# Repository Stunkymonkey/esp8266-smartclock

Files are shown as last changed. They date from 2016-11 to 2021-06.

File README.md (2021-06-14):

# esp8266-smartclock

We started designing and building a small clock that is connected to your local Wifi and controls your home using cheap 433Mhz power outlets. The ESP8266 operates as a relay to communicate with your power outlets.

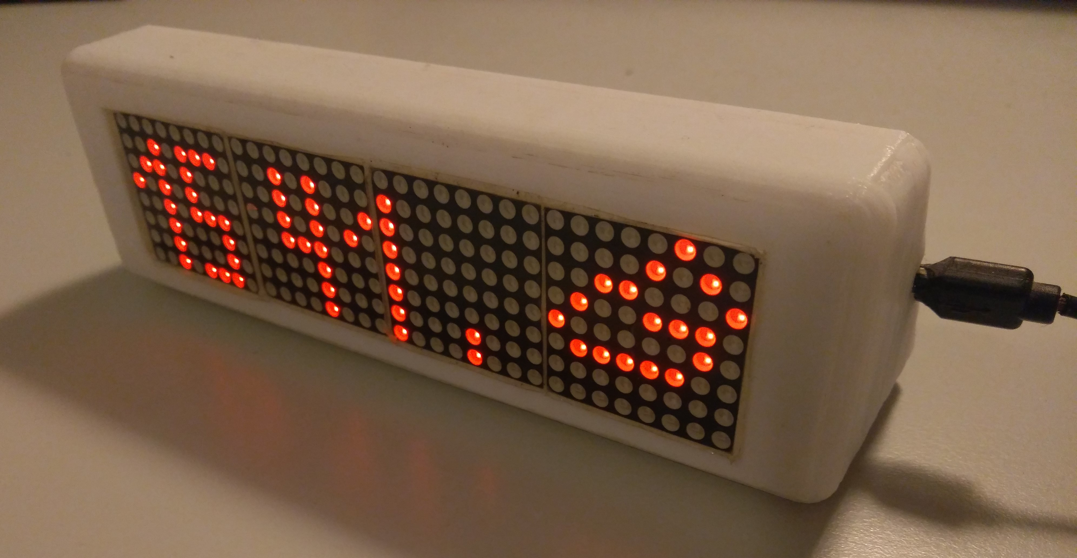
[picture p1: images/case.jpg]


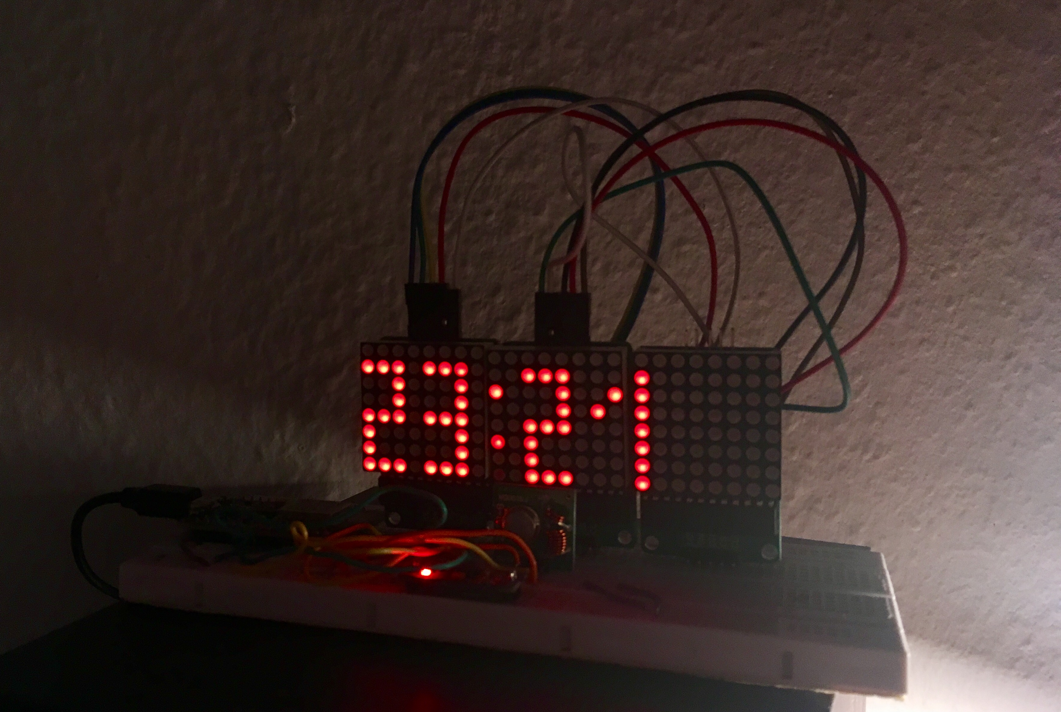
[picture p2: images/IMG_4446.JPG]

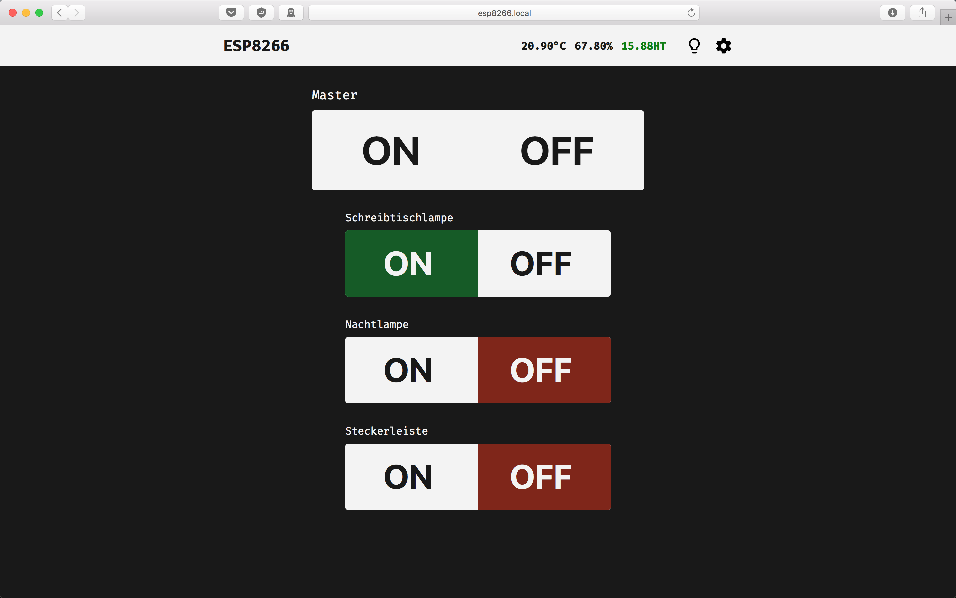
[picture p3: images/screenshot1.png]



## Hardware
The total costs are around 25€:

* NodeMCU board with the ESP8266 and an USB programmer
* DHT11 or DHT22 (optional)
* 433Mhz transmitter (XD-RF-5V)
* 4x MAX7219 based 8x8 led matrix
* 433mhz Wireless Remote Control Electrical Outlet Switch (<a href="https://www.amazon.de/dp/B001AX8QUM/ref=cm_sw_em_r_mt_dp_Abo7zbDRGS07B">example</a>) 
* some wires

### Schematic
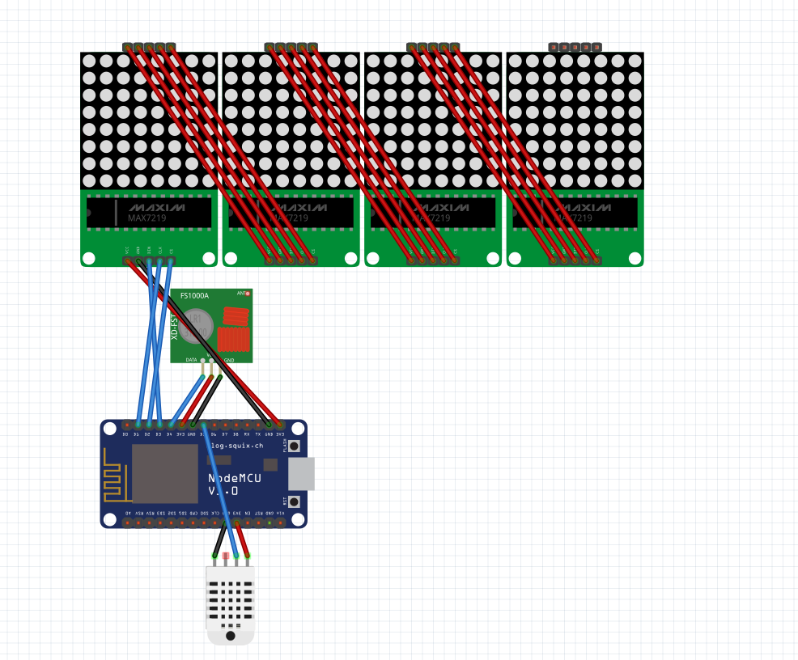
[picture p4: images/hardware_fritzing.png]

<a href="esp8266_smartclock.fzz">Fritzing File</a>

## Features
* opens an access point to enter your local Wifi SSID and password
* customisable slots for your power outlets
* custom brightness settings for the LED matrix
* Read Data from a DHT11 temperature and humidity sensor and send it to a remote Host (for saving the data see: sensor.php)
* NTP Time support
* supports multiple Wireless Remote Control protocols (we are using the <a href="https://github.com/sui77/rc-switch">rc-switch</a> library)
* dyndns (using a get request on a given url every 10 minutes)
* password-authentication for user from the internet (no https 😞)
* OverTheAir Update

## Development

### Dependencies

| Module | last tested version |
| --- | --- |
| [ESP8266](https://github.com/esp8266/Arduino) | 2.7.1 |
| [NTPClient](https://github.com/arduino-libraries/NTPClient)  | 3.2.0 |
| [Adafruit_Sensor](https://github.com/adafruit/Adafruit_Sensor) | 1.1.3 |
| [DHT-sensor-library](https://github.com/adafruit/DHT-sensor-library) | 1.3.10 |
| [LedControl](http://wayoda.github.io/LedControl/) | 1.0.6 |
| [rc-switch](https://github.com/sui77/rc-switch) | 2.6.3 |
| [Time](http://playground.arduino.cc/code/time) | 1.6.0 |

### Board-Settings (used)

- Board: NodeMCU 1.0 (ESP-12E Module)
- Builtin Led: 2
- Upload Speed: 115200
- CPU Frequency: 80Mhz
- Flash Size: 4MB (FS:1MB OTA:~1019KB)
- Debug Port: Disabled
- Debug Level: None
- lwIP Variant: v2 Lower Memory
- VTables: Flash
- Exceptions: Enabled
- Erase Flash: Only Sketch
- SSL Support: All SSL ciphers (most compatible)

### Compile
```
arduino ./ESP_clock/ESP_clock.ino --verify --preserve-temp-files
```

### Update via OTA
```
curl -u admin:admin -F "image=@$(find /tmp/arduino* -name 'ESP_clock.ino.bin')" esp8266/update
```
or via webinterface at `http://esp8266/update`

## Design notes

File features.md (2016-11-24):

+ Steckdosen an/auschalten [HTTP, Webseite]
+ Pixel an/auschalten [HTTP, Webseite]
+ Konfiguration im EEPROM:
	+ Steckdosen bennenen
	+ initalier AP zur Eingabe von SSID und Pwd

+ Uhrzeit via NTP abfragen
	+ Uhrzeit auf Display anzeigen
	+ Konfiguration
+ Temperatur und Feuchtigkeit auslesen und per API zur Verfügung stellen
+ startup animation
+ Hardware Switch mit (programmierbarer Aktion)

## Optional:

+ Helligkeit messen
+ sockets delayed auschalten

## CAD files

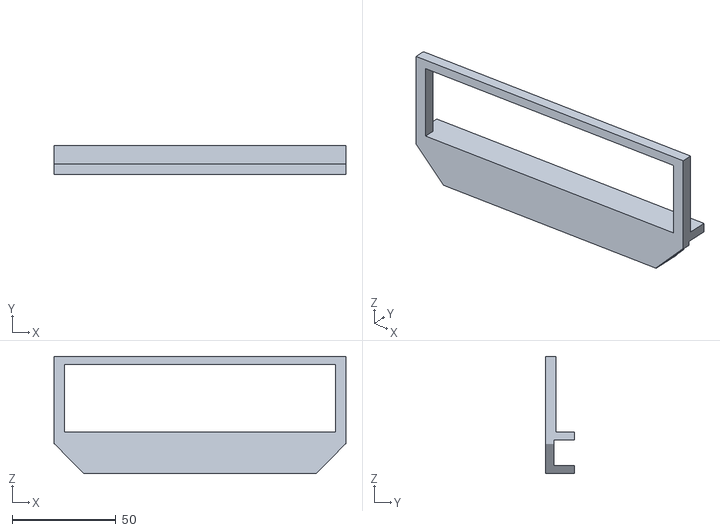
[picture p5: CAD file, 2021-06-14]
3d-printing/smartclock_case_to_mount_on_plank.stl
140.5 x 14.0 x 56.5

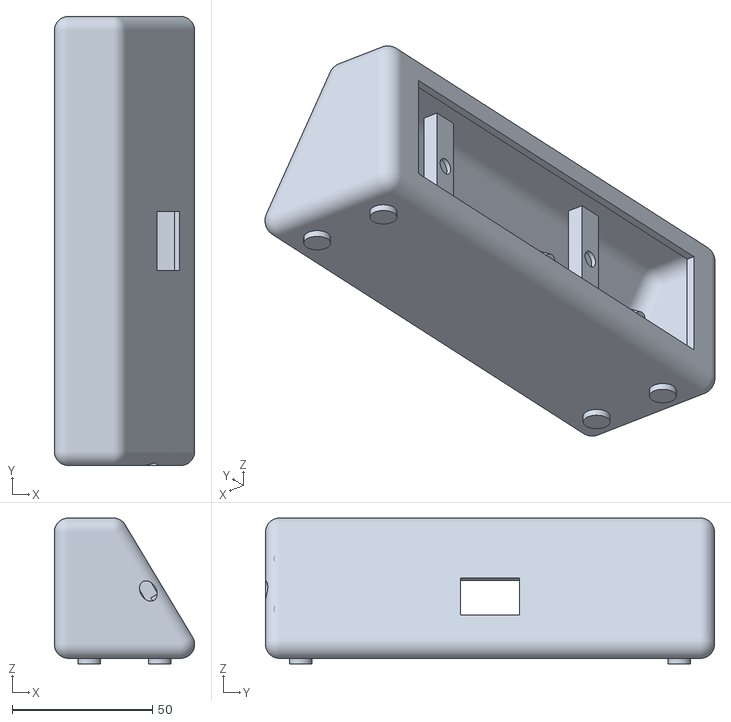
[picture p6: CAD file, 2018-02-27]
3d-printing/smartclock.stl
50.0 x 160.0 x 52.0

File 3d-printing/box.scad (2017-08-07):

$fn=30;

// x = height
// y = widht
// zb = depth bottom
// zt = depth top
// t = thikness
// r = radius of round corner
// dispx = display height
// dispy = display width
// side = {true == left / false == right}
module box(x, y, zb, zt, t, r, dispx, dispy, side) {
    angle = atan(x/(zb-zt));
    new_x = x-2*r;
    new_y = y-2*r;
    new_zb = zb-2*r;
    move_of_hollow = (zb/2)/cos(90-angle);
    difference(){
        minkowski(){
            difference(){
                cube([new_x,new_y,new_zb], center = true);
                translate([move_of_hollow+(new_zb/2),0,-(new_x/2)])
                    rotate(angle, [0, 1, 0])
                        cube([10*x,y+1,zb], center = true);
            }
            sphere(r);
        }
        
        //Cut out ledge
        translate ([(-zb/2)+1,0,0]) cube([10, dispy, dispx], center = true);
        
        //Hollow inside
        minkowski(){
            difference(){
                cube([new_x-2*t,new_y-2*t,new_zb-2*t], center = true);
                translate([move_of_hollow+(new_zb/2-2*t),0,-(new_x/2)])
                    rotate(angle, [0, 1, 0])
                        cube([10*x-2*t,y+1-2*t,zb-2*t+0.5], center = true);
            }
            sphere(r);
        }
        
        side_position = side ? y/2 : -y/2 ;
        translate([0, side_position, -zb/10])
            rotate(angle, [0, 1, 0])
            rotate(90, [1, 0, 0])
                linear_extrude(height = r*2, center = true, convexity = 10, twist = 0)
                    scale([(sqrt(2)/2)*1.1,(sqrt(2)/2)*0.8,1])
                        circle(r = 5);
        
//        translate([x/2-1,0,-(new_x/2)])
//            rotate(angle, [0, 1, 0])
//                cube([90, new_y-2*r, 2], center = true);
//        translate([x/2,0,-(new_x/2)])
//            rotate(angle, [0, 1, 0])
//                cube([90, new_y-4*r, 2], center = true);
        
        //cube([new_x*2, new_y*0.2, new_zb*2], center = true);
    }
    translate([10, y/4, 0])
        rotate(180+angle, [0, 1, 0])
                esp_mount(3, 2);
    translate([0, 0, -zb/2])
        stands(4, 2, 10, x, y, zb, 10);
}

// height_front = front distance to floor
// height_back = back distance to floor
// diameter = radius of stands
// x = size of bottom in x
// y = size of bottom in y
// zb = size of bottom in z
// distance = position: distance from edges
module stands(height_front, height_back, diameter, x, y, zb, distance) {
    difference() {
        union(){
            translate([-x/2+distance, y/2-distance,-height_front/2])
                cylinder(d=diameter, h=height_front, center=true);
            translate([+x/2-distance, y/2-distance,-height_front/2])
                cylinder(d=diameter, h=height_front, center=true);
            translate([-x/2+distance, -y/2+distance,-height_front/2])
                cylinder(d=diameter, h=height_front, center=true);
            translate([+x/2-distance, -y/2+distance,-height_front/2])
                cylinder(d=diameter, h=height_front, center=true);
        }
        angle = atan((height_front-height_back)/zb);
        translate([-x/2, 0, -zb/2-(height_front)])
            rotate(angle, [0, -1, 0])
                cube([x*2, y, zb], center=true);
    }
}

module esp_mount(height, depth) {
    XDim = 25.0;
    YDim = 48.0;
    HD = 2.5; //are in reality 3.0
    hole_size = 1.5;
    HXO = 2.0;
    HYO = 2.2;
    difference() {
        translate([-XDim/2+HXO, YDim/2-HYO,0])
            cylinder(d=HD, h=height*2, center=true);
        translate([-XDim/2+HXO, YDim/2-HYO,2*height-depth])
            cylinder(d=hole_size, h=height*2, center=true);
    }
    difference() {
        translate([XDim/2-HXO, YDim/2-HYO,0])
            cylinder(d=HD, h=height*2, center=true);
        translate([XDim/2-HXO, YDim/2-HYO,2*height-depth])
            cylinder(d=hole_size, h=height*2, center=true);
    }
    difference() {
        translate([-XDim/2+HXO, -YDim/2+HYO,0])
            cylinder(d=HD, h=height*2, center=true);
        translate([-XDim/2+HXO, -YDim/2+HYO,2*height-depth])
            cylinder(d=hole_size, h=height*2, center=true);
    }
    difference() {
        translate([XDim/2-HXO, -YDim/2+HYO,0])
            cylinder(d=HD, h=height*2, center=true);
        translate([XDim/2-HXO, -YDim/2+HYO,2*height-depth])
            cylinder(d=hole_size, h=height*2, center=true);
    }
}

box(50, 160, 50, 20, 2, 5, 32, 133, true);

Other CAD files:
3d-printing/smartclock.scad

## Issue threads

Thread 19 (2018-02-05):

On/Off - Button have white corners

Stunkymonkey, 2018-02-05:
if they are red i noticed, that they have a white corner
maybe also if they are green

Stunkymonkey, 2018-02-05:
green is also affected

Stunkymonkey, 2019-07-13:
rendering issue

Closed 2019-07-13.

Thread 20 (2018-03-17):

Boot Loop Crash

friedrichweise, 2018-03-17:
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

Stunkymonkey, 2018-03-30:
still not working?

friedrichweise, 2018-04-14:
Fixed by formatting the file system.

friedrichweise, 2018-04-14:
linked to https://github.com/esp8266/Arduino/issues/4417

Closed 2018-12-28.

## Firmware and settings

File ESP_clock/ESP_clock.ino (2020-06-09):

// IMPORTS
extern "C" {
#include "user_interface.h"
}
#include <ArduinoOTA.h>
#include <DHT.h>
#include <DNSServer.h>
#include <ESP8266HTTPClient.h>
#include <ESP8266HTTPUpdateServer.h>
#include <ESP8266mDNS.h>
#include <ESP8266WebServer.h>
#include <ESP8266WiFi.h>
#include <FS.h>
#include <LedControl.h>
#include <LittleFS.h>
#include <NTPClient.h>
#include <RCSwitch.h>
#include <SoftwareSerial.h>
#include <TimeLib.h>
#include <WiFiClient.h>
#include <WiFiClientSecure.h>
#include <WiFiUdp.h>

//include personal config
#include "config.h"
#include "victron.h"

// GLOBAL VARIABLES
String deviceName = "";

String WifiSsid = "";
String WifiPw = "";

String configSocketSets[SOCKET_AMOUNT][5];
boolean statusSocketSets[SOCKET_AMOUNT];

LedControl lc = LedControl(LED_MATRIX_PORT_DATA,        LED_MATRIX_PORT_CLK, \
                           LED_MATRIX_PORT_CHIP_SELECT, LED_MATRIX_PORT_AMOUNT);
int led_matrix_intensity;
boolean MatrixStatus = true;

int prevMin1 = -1;
int prevMin2 = -1;
int prevHour1 = -1;
int prevHour2 = -1;
int prevWeather = 12;
int prevSecond = -1;
boolean prevBlink = false;

boolean isAPMode = false;

ESP8266WebServer server(80);
//used to combine webpages in createServer();
String content;
String DEBUG_STRING = "";

//OTA-Server
ESP8266HTTPUpdateServer httpUpdater;

//AP-Settings
DNSServer dnsServer;

//Socket-remote
RCSwitch mySwitch = RCSwitch();

//Temperature and Humidity
DHT dht(SENSOR_PORT, SENSOR_TYPE);
float humidity, temperature, heatindex;

//NTP
WiFiUDP ntpUDP;
NTPClient timeClient(ntpUDP, NTP_SERVER, 0, NTP_INTERVAL);

//HTTP
std::unique_ptr<BearSSL::WiFiClientSecure> client_secure(new BearSSL::WiFiClientSecure);
WiFiClient client;
HTTPClient http;

//WEATHER
int weatherStatus = -1;

void (* Disco_Functions[3])(void);
bool DiscoStatus = false;
int DiscoState = 0;
int DiscoTmp = 0; //shared storage for all disco-functions

// Victron
SoftwareSerial victronSerial(VICTRON_RX, VICTRON_TX);
char receivedChars[buffsize];
char tempChars[buffsize];
char recv_label[num_keywords][label_bytes]  = {0};
char recv_value[num_keywords][value_bytes]  = {0};
char value[num_keywords][value_bytes]       = {0};
static byte blockindex = 0;
bool new_data = false;
bool blockend = false;

void setup()
{
  //Serial-Output
  if (DEBUG) {
    Serial.begin(115200);
  }
  print("Starting setup");
  // start vicront serial
  if (ENABLE_VICTRON) {
    victronSerial.begin(19200);
  }
  //enable LEDs
  pinMode(LED_BUILTIN, OUTPUT);
  pinMode(2, OUTPUT);
  LEDOn();
  WifiLEDOff();
  setProgress(266 / 8593.0);

  //mount File-System
  bool mountFs = LittleFS.begin();
  if (!mountFs) {
    print("Failed to mount File-System!");
  }
  setProgress(341 / 8593.0);

  //init Led-Matrixes:
  if (ENABLE_MATRIX) {
    led_matrix_intensity = loadIntensity();
    initMatrix(led_matrix_intensity);
  }
  setProgress(348 / 8593.0);

  //load device Name
  deviceName = loadDeviceName();
  setProgress(434 / 8593.0);
  //load sockets
  if (ENABLE_SOCKETS) {
    loadSocketSets();
  }
  setProgress(510 / 8593.0);

  //init wifi access point
  initWifi();
  setProgress(7213 / 8593.0);

  //network stuff
  createServer();
  setProgress(7229 / 8593.0);

  // OTA enable
  if (ENABLE_OTA) {
    httpUpdater.setup(&server, "/update", OTA_USERNAME, OTA_PASSWORD);
  }
  setProgress(7230 / 8593.0);

  // Http-Server start
  server.begin();
  setProgress(7247 / 8593.0);

  //service announcement
  if (ENABLE_MDNS) {
    // currently there is a bug, so this should be change back in the future to:
    // MDNS.begin(deviceName)
    if (!MDNS.begin(deviceName, WiFi.localIP(), 120)) {
      print("Error setting up MDNS responder!");
    }
    //WiFi.localIP().toString()
    MDNS.addService("http", "tcp", 80);
    MDNS.notifyAPChange();
  }

  //NTP-init
  timeClient.begin();
  timeClient.forceUpdate();
  timeClient.setTimeOffset(calculate_offset());
  setProgress(7319 / 8593.0);

  //RC-Switch
  if (ENABLE_SOCKETS) {
    mySwitch.enableTransmit(SOCKET_PORT);
  }

  if (ENABLE_SENSOR) {
    dht.begin();
    getTemperature();
  }
  setProgress(7593 / 8593.0);

  sendSensorData();
  setProgress(7702 / 8593.0);

  getWeatherInfo();
  setProgress(7814 / 8593.0);

  updateDYNDNS();
  setProgress(8265 / 8593.0);

  // fingerprint verification is skipped
  client_secure->setInsecure();

  Disco_Functions[0] = { random_pixel };
  Disco_Functions[1] = { cosine_wave };
  Disco_Functions[2] = { waterworld };
  LEDOff();
  WifiLEDOff();
  setProgress(1.0);
  //yolo();
}


void loop()
{
  server.handleClient();
  if (ENABLE_MDNS) {
    MDNS.update();
  }
  getTemperature();
  if (!isAPMode) {
    timeClient.update();
    timeClient.setTimeOffset(calculate_offset());
    sendSensorData();
    getWeatherInfo();
    updateDYNDNS();
  }
  victron();
  if (ENABLE_MATRIX && MatrixStatus) {
    if (!DiscoStatus) {
      drawTime();
      drawSecondsGraph();
      drawWeather(weatherStatus, 3);
    } else {
      draw_disco();
    }
  }
}

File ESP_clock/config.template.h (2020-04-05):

//PERSONAL-CONFIG-FILE

//DEBUG
const bool    DEBUG = false;
const unsigned int     REACTION_TIME = 500;

//SERVICES
const bool    ENABLE_SOCKETS = true;
const bool    ENABLE_SENSOR = true;
const bool    ENABLE_POST_SENSOR_DATA = false;
const bool    ENABLE_MATRIX = true;
const bool    ENABLE_DYNDNS = false;
const bool    ENABLE_MDNS = false;
const bool    ENABLE_LOGIN = true;
const bool    ENABLE_LOCAL_NO_LOGIN = true;
const bool    ENABLE_OTA = true;
const bool    ENABLE_WEATHER = true;
const bool    ENABLE_VICTRON = false;

//DEVICE-NAME
const String  DEFAULT_DEVICE_NAME = "ESP8266";

//LOGIN
const char    WWW_USERNAME[] = "admin";
const char    WWW_PASSWORD[] = "password";

//FIRMWARE
const char    OTA_USERNAME[] = "admin";
const char    OTA_PASSWORD[] = "admin";

//NTP
const char    NTP_SERVER[] = "pool.ntp.org";
const int     NTP_TIMEZONE = 1;     // Central European Time
//const int     NTP_TIMEZONE = -5;  // Eastern Standard Time (USA)
//const int     NTP_TIMEZONE = -4;  // Eastern Daylight Time (USA)
//const int     NTP_TIMEZONE = -8;  // Pacific Standard Time (USA)
//const int     NTP_TIMEZONE = -7;  // Pacific Daylight Time (USA)
const int     NTP_INTERVAL = 600000; // every 10 minutes
const bool    NTP_DST = true; //Daylight saving time

//LED-Matrix
const int     LED_MATRIX_INTENSITY = 15;
const int     LED_MATRIX_DIRECTION = 0; // 0=bottom, 1=right, 2=top, 3=left
const int     LED_MATRIX_PORT_DATA = D3;
const int     LED_MATRIX_PORT_CHIP_SELECT = D2;
const int     LED_MATRIX_PORT_CLK = D1;
const int     LED_MATRIX_PORT_AMOUNT = 3;

//REMOTE-SOCKET
const int     SOCKET_PORT = D4;
const int     SOCKET_AMOUNT = 3;

//TEMPERATURE AND HUMIDITY
const int     SENSOR_PORT = D5;
const int     SENSOR_TYPE = DHT11;
const long    SENSOR_INTERVAL = 2000; //in ms
const String  POST_SENSOR_DATA_ENDPOINT = "someurl";
const String  POST_SENSOR_DATA_TOKEN = "sometoken";
const long    POST_SENSOR_INTERVAL = 1800000; // in ms (every 30 minutes)

//DYNDNS
const long    DYNDNS_INTERVAL = 60000; // in ms (every 10 minutes)
const String  DYNDNS_URL = "http://freedns.afraid.org/dynamic/update.php?asdf...";

//WEATHER
const long    GET_WEATHER_INTERVAL = 1800000; // in ms (every 30 minutes)
const String  WEATHER_CITY = "London,uk";
const String  WEATHER_API_TOKEN = "asdasdewqrsv..."; // api.openweathermap.org
const int     WEATHER_3HOUR_FUTURE = 2; // gives the weather time in the future: 1 current quarter, 2 next quarter, ..

//VICTRON
const int     VICTRON_RX = D7;
const int     VICTRON_TX = D8;

//################################################################
// DO NOT CHANGE THINGS BELOW, UNLESS YOU KNOW WHAT YOU ARE DOING

//STORAGE
/* File structure:
   /NAME_CONFIG_PATH:
      name
   /WIFI_CONFIG_PATH:
      ssid \n
      pw
   /sockets/$id:
      protocol (v3 = true; v1 = false)
      socketName;
      houseCode;
      groupCode;
      socketCode;
*/
const String  WIFI_CONFIG_PATH = "/wifi.txt";
const String  NAME_CONFIG_PATH = "/name.txt";
const String  LED_CONFIG_PATH = "/led.txt";
const String  SOCKET_CONFIG_PATH = "/sockets/";

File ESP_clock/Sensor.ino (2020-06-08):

/*
   read temperature from sensor
*/
void getTemperature() {
  if (ENABLE_SENSOR) {
    static unsigned long sensorPreviousMillis;
    unsigned long currentMillis = millis();
    if (currentMillis - sensorPreviousMillis >= SENSOR_INTERVAL || sensorPreviousMillis == 0) {
      sensorPreviousMillis = currentMillis;
      float temp;
      temp = dht.readTemperature();
      if (!isnan(temp)) {
        temperature = temp;
      } else {
        print("Failed to read temperature from DHT sensor!");
      }
      temp = dht.readHumidity();
      if (!isnan(temp)) {
        humidity = temp;
      } else {
        print("Failed to read humidity from DHT sensor!");
      }
      temp = dht.computeHeatIndex(temperature, humidity);
      if (!isnan(temp)) {
        heatindex = temp;
      } else {
        print("Failed to calculate heatindex!");
      }
    }
  }
}

/*
   calculate if it hits critical values => changes color
*/
int get_heat_index_level() {
  if (heatindex < 27) {
    return 0;
  } else if (heatindex >= 27 && heatindex < 32) {
    return 1;
  } else if (heatindex >= 32 && heatindex < 40) {
    return 2;
  } else if (heatindex >= 40 && heatindex < 54) {
    return 3;
  } else if (heatindex >= 54) {
    return 4;
  }
  return -1;
}

/*
   sending your data via json request
*/
void sendSensorData() {
  if (ENABLE_POST_SENSOR_DATA && !isAPMode) {
    static unsigned long postSensorPreviousMillis;
    unsigned long currentMillis = millis();
    if (currentMillis - postSensorPreviousMillis >= POST_SENSOR_INTERVAL || postSensorPreviousMillis == 0) {
      postSensorPreviousMillis = currentMillis;

      String message = "{\"temp\":\"" + String(temperature) + "\", \"humidity\":\"" + String(humidity) + "\"}";
      if (POST_SENSOR_DATA_ENDPOINT.startsWith("https")) {
        http.begin(*client_secure, POST_SENSOR_DATA_ENDPOINT);
      } else {
        http.begin(client, POST_SENSOR_DATA_ENDPOINT);
      }
      http.addHeader("Content-Type", "application/json");
      http.addHeader("token", POST_SENSOR_DATA_TOKEN);
      int httpCode = http.POST(message);
      if (httpCode > 0) {
        if (DEBUG && (httpCode == HTTP_CODE_OK || httpCode == HTTP_CODE_MOVED_PERMANENTLY)) {
          http.writeToStream(&Serial);
          print("");
        }
      } else {
        Serial.printf("HTTP Sensor-POST failed, error: %s\n", http.errorToString(httpCode).c_str());
      }
      http.end();
    }
  }
}

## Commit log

2016-03-16 Changed LedControl library
    This fork contains a fix specifically for the ESP8266
2016-10-28 add menu and socket inputs
2016-10-28 [server-base] added socket-config reading and file reading bug fix
    [ESP_clock.ino, Helpers.ino, Sockets.ino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]
2016-10-28 load sockets
2016-10-28 output socket values in settings
2016-10-29 better output & added: rc-sockets, ntp-client
2016-10-31 fixed redirects to specific path
    [Webserver.ino]
2016-10-31 fixed escaping bug with quotes
    [Webserver.ino]
2016-10-31 added protocol v1 for cookingrobot, but there is still an unknown error
    [ESP_clock.ino, Sockets.ino, Webserver.ino]
2016-11-01 fixed friedls socket, new special feature: turning on works... but not off
    [Webserver.ino]
2016-11-01 added onboard-led support
2016-11-01 fixed loop in reading lines of sockets
    [Sockets.ino]
2016-11-11 fixed range bug when saving socket
    [Sockets.ino, Webserver.ino]
2016-11-17 added toggle option for sockets
2016-11-18 added correct host-name for good dns resolution
    [ESP_clock.ino, Wifi.ino]
2016-11-18 added option for blue-LED & rearanged a bit settings
2016-11-19 added temperatur and humidity sensor
2016-11-19 fixed return of intensitySet
    [Matrix.ino]
2016-11-19 printing names instead of ids
2016-11-24 first unstable implementation of watch
    [ESP_clock.ino, Matrix.ino]
2016-11-26 fixed matrix-service was missing & small socket-service fix
    [ESP_clock.ino, Matrix.ino, config.template.h]
2016-11-26 socket service added in settings
2016-11-26 socket service added in settings (forgot to add something)
2016-11-26 add led pins to config
2016-11-26 renamed folder and fixed const int of intensity
    [ESP_clock.ino, Helpers.ino, Matrix.ino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]
2016-11-26 simplified socket-functions
2017-01-12 working version for simple switches by saving two strings
2017-01-15 fixed wrong blue light after redirect
    [Webserver.ino]
2017-01-15 add json api ednpoint for sensor data
2017-01-17 small design fixes; add hint to broken socketAmount setting
    [Webserver.ino, config.template.h]
2017-01-17 realign sensor data
2017-01-19 try fixing wrong reading of save-socket bug
    [Sockets.ino]
2017-05-29 added colors for heat-index and general levels
2017-06-26 add option to send sensor value via HTTP POST to server; fix read lines bug
    [ESP_clock.ino, Sensor.ino, Sockets.ino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]
2017-06-26 add missing bracket and fix n++ notation
    [Sensor.ino, Sockets.ino]
2017-07-15 added intervall for sending temperatur and humidty
2017-07-15 added option for rotating led Matrixes
2017-07-16 fix: weather, dyndns, weather now run once at boot
    [Sensor.ino, Weather.ino, Wifi.ino]
2017-07-17 added new option for disable the led lights temporary
2017-07-18 initial 3d-print box
    [box.scad]
2017-07-19 after weather error it will get refreshed every 10 minutes
    [Weather.ino]
2017-07-22 fixed weather feature now using less ram
    [ESP_clock.ino, Sensor.ino, Weather.ino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]
2017-07-27 3d-print: fixed total size of box
    [box.scad]
2017-07-30 fixed scaling problem
    [box.scad]
2017-08-02 added hole for usb cable
    [box.scad]
2017-08-02 added missing ESP8266 scad-models
    [ESP8266Models.scad]
2017-08-03 added esp mounts and stands on bottom
    [box.scad]
2017-08-03 remove old esp library because it was not used
    [ESP8266Models.scad, box.scad]
2017-08-07 intial back-plate, but not sure if we are using it
    [box.scad]
2017-08-07 fixed summer-/winter-time, but led-drawings are still old
    [ESP_clock.ino, Sensor.ino, Time.ino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]
2017-08-07 switched drawing using the new time library
2017-08-08 fixed issue when 0 needs to be printed
    [ESP_clock.ino]
2017-08-12 fixed missing redraw after clearing
    [Matrix.ino]
2017-08-12 removed wrong 0 in template file
    [config.template.h]
2017-08-12 fixed missing authentication in saving sockets
    [Sockets.ino]
2017-08-12 added restart button
2017-08-14 if esp boots in ap mode some features that will not work are disabled
    [ESP_clock.ino, Sensor.ino, Weather.ino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]
2017-09-08 hopfully fixing a crash that happens every 4 days
    [Matrix.ino, Weather.ino]
2017-10-22 add fritzing file
    [esp8266_smartclock.fzz]
2017-10-22 update schematic
    [esp8266_smartclock.fzz]
2017-11-12 added master switch
2017-11-13 dht now variable && fixed master socket on/off
    [ESP_clock.ino, Sockets.ino, Webserver.ino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]
2017-11-19 sensor now keeps data if it fails to read
    [Sensor.ino]
2017-11-22 improve navigation bar on mobile devices
2017-11-22 [3d-print] added cubes to prevent display from falling in & rearanged esp position
    [smartclock.scad]
2017-12-16 added open space for dht22 & fixed hohles for esp8266
    [smartclock.scad]
2017-12-16 fixed carrier of display not only being connected on one side
    [smartclock.scad]
2018-01-06 [dyndns] if it fails, do it less often
    [Wifi.ino]
2018-01-28 update 3d-model having esp on the right
    [smartclock.scad, smartclock.stl]
2018-01-28 [3d-printing] add slot for 433mhz module
    [smartclock.scad, smartclock.stl]
2018-01-28 [weather] fix ram overflow
    [Weather.ino]
2018-01-29 [3d-printing] change size of stands
    [smartclock.scad]
2018-01-29 update stl file
    [smartclock.stl]
2018-02-05 fix matrix-numbers when changing brightness
    [Matrix.ino]
2018-02-27 fixing 3d-printing problem
    [smartclock.scad, smartclock.stl]
2019-07-26 [esp_clock] redo weather get-request to have less fragmentation and thereby less crashes
    [ESP_clock.ino, Helpers.ino, Weather.ino]
2019-07-26 [esp_clock] better error messages for dyndns
    [Wifi.ino]
2020-03-04 fix mDNS in newer versions
    [ESP_clock.ino]
2020-04-03 fix mixed up NTP-interval seconds
    [config.template.h]
2020-04-05 [time] calculate offset without current time
2020-04-05 [mDNS] small fix for newer version
    [ESP_clock.ino]
2020-06-08 Github actions (#23)
    * try github-actions
    * [actions] copy config
    * [actions] adjust board name
    * [actions] adjust flashsize
2020-06-09 replace SPIFFS with LittleFS
    [ESP_clock.ino, Helpers.ino, Matrix.ino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]
2020-11-18 add image with case
2021-06-13 fix String-array copy by accessing it directly
    [Webserver.ino]
2021-06-14 added 3D case in stl format and included image in readme
    [smartclock_case_to_mount_on_plank.stl]
